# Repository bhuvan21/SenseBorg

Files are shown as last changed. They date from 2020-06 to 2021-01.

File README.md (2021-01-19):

# SenseBorg
A modular platform for human sensory substitution via haptic feedback.

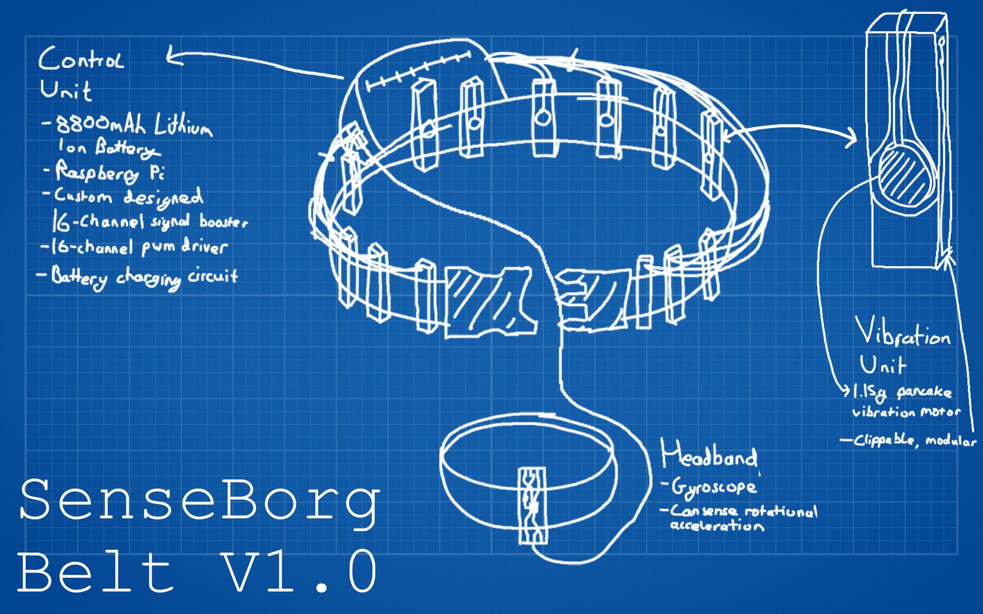
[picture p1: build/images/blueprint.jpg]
Blueprint


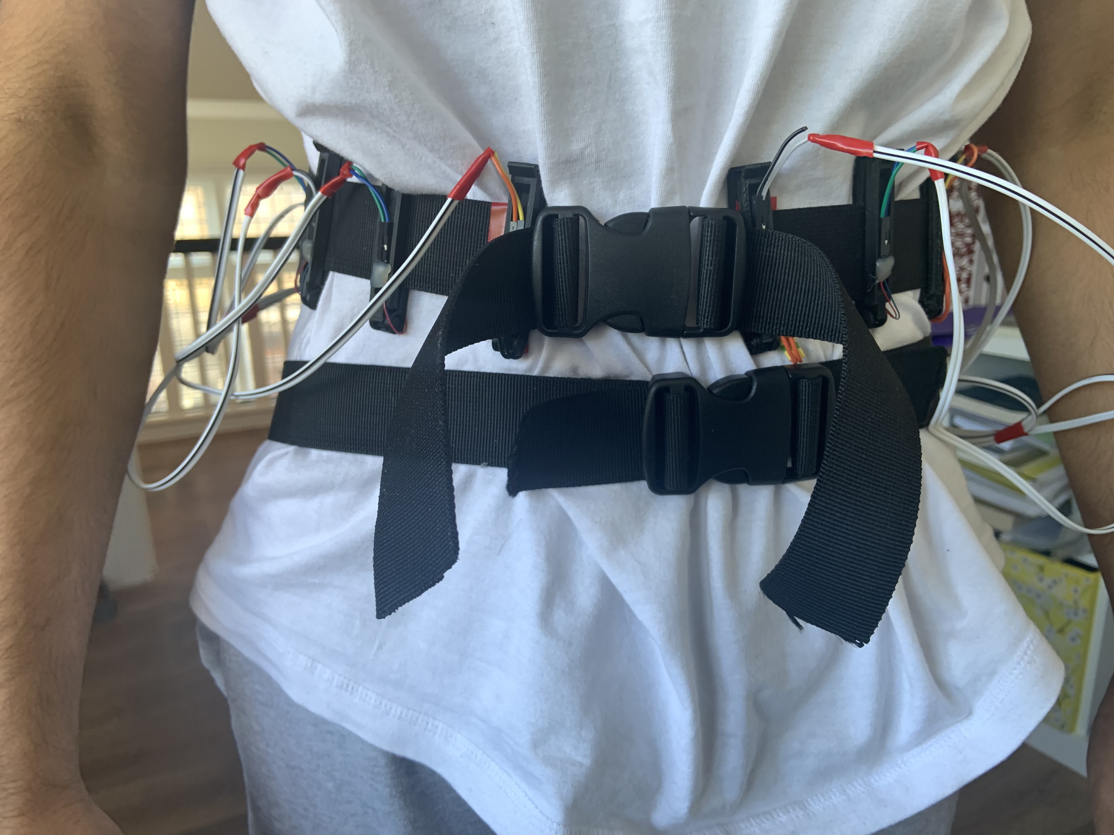
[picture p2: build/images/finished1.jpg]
Finished


## Introduction
The concept of sensory substitution involves supplying sensory stimuli through a sensory modality usually used for gathering different sensory data  – and has an important role to play in rehabilitation those with vestibular impairments. Sensory substitution requires the use of a specific device, which uses artificial sensors to collect sensory data, and delivers this data to a subject via one of their sensory modalities (e.g touch, audio, visual). Devices which do this are called sensory substitution devices (SSDs).

## The Project
Sensory Substitution Devices require two parts.  
1. Some way to provide artificial stimuli  
2. Some way to generate this stimuli (usually a sensor of some kind)  

Good examples of this are the BrainPort and feelSpace belt devices. My project nicknamed "SenseBorg" (think Senses + Cyborg) is my contribution to this under-explored area of research.  

These two parts of my project are:
1. A custom belt, with up to 16 embedded haptic motors, for generating artificial stimuli with selectable position and strength.  
2. An IMU headband for sensing rotational acceleration, as an approximation of the sense of balance.  

The second part of the project can be easily substituted for any other sensor, which could be used to conduct experiments into learning other sensorimotor contingencies.  
Thus, this project provides a platform for providing artificial stimuli for use in more general sensory substitution experiments.

## The Belt
The specifics of the physical hardware in the SenseBorg belt is more detailed in the build folder, specifically BUILD.md. However, the basic features are as follows.  
- 12h battery life
- 16 different motor channels, each with PWM control
- Wifi enabled
- Bluetooth capabilities
- Modular as haptic motors can be placed variably on the belt to accomodate for different waist sizes
- ~2A Charging rate (if your charger can handle it) for overnight charging

## This Repository
This repository contains the software and hardware information for the SenseBorg belt itself. Of course, a lot of the software is specific to interfacing with my specific sensor system, and translating this into targeted haptic feedback. Please have a look at build/BUILD.md for a build guide. This project is currently in it's first iteration, so is subject to change and improvement.

## Results
After a first experiment, the hypothesis that the wearing of this belt would result in an increase in the wearer's sense of balance, was shown to be statistically significant. (Balance was tested via a sharpened Romberg Test, the belt was worn over a week period for 12 hours a day, the statistical difference was measured via a T-test, and the final p < 0.01)
My research paper based on this device is undergoing a final review at the Young Scientists Journal.

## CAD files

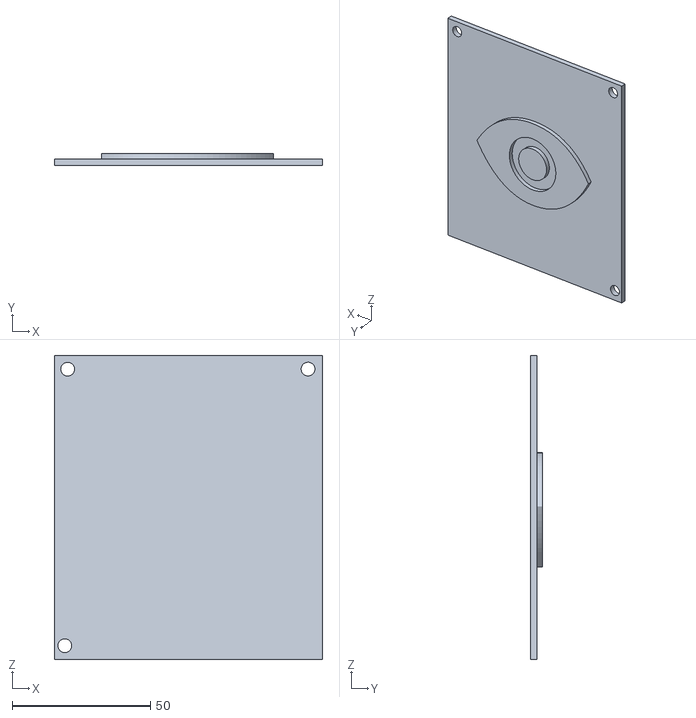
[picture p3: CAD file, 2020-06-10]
build/stls/top.stl
97.0 x 4.50 x 110.0

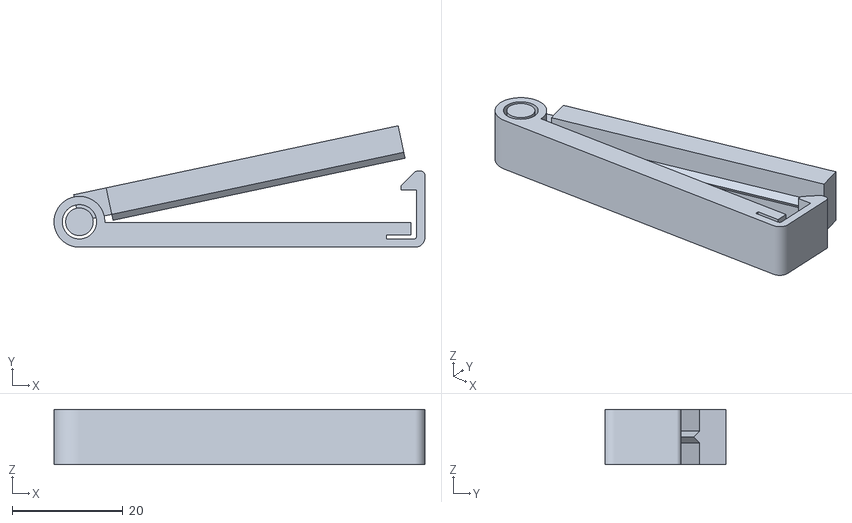
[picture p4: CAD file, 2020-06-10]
build/stls/clip.stl
67.1 x 22.0 x 10.0

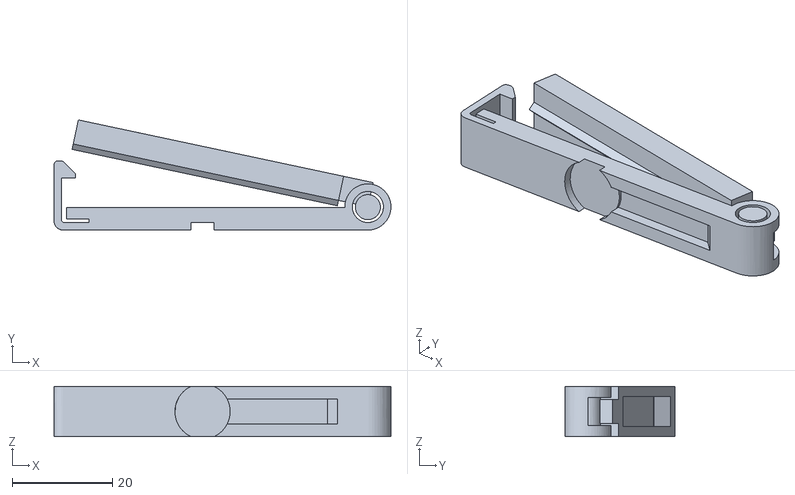
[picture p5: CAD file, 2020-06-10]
build/stls/motorclip.stl
67.1 x 21.9 x 10.0

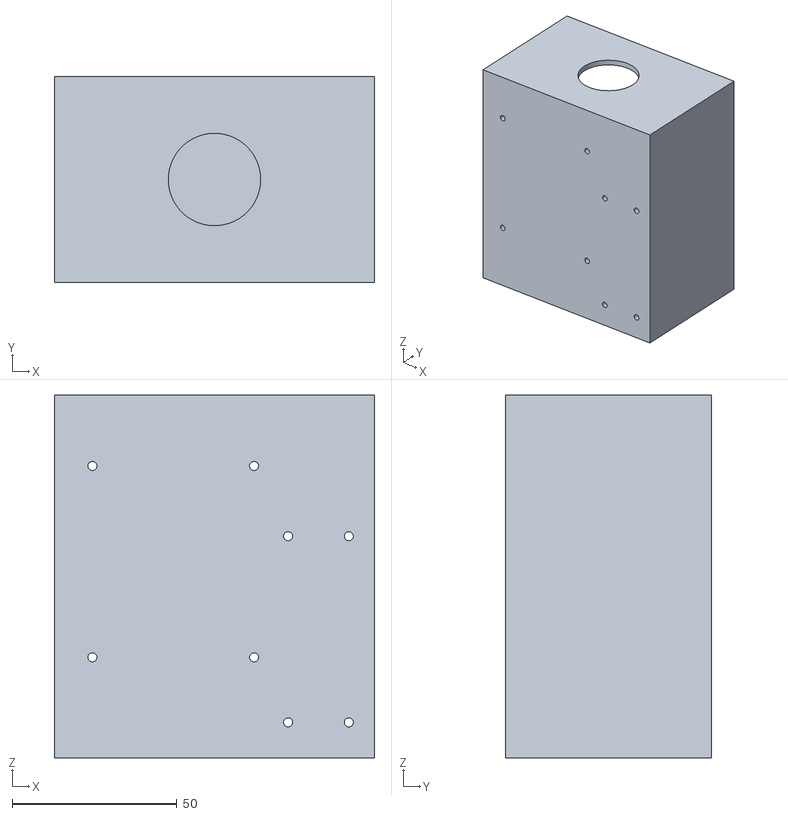
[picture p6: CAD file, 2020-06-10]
build/stls/box.stl
97.0 x 62.5 x 110.0

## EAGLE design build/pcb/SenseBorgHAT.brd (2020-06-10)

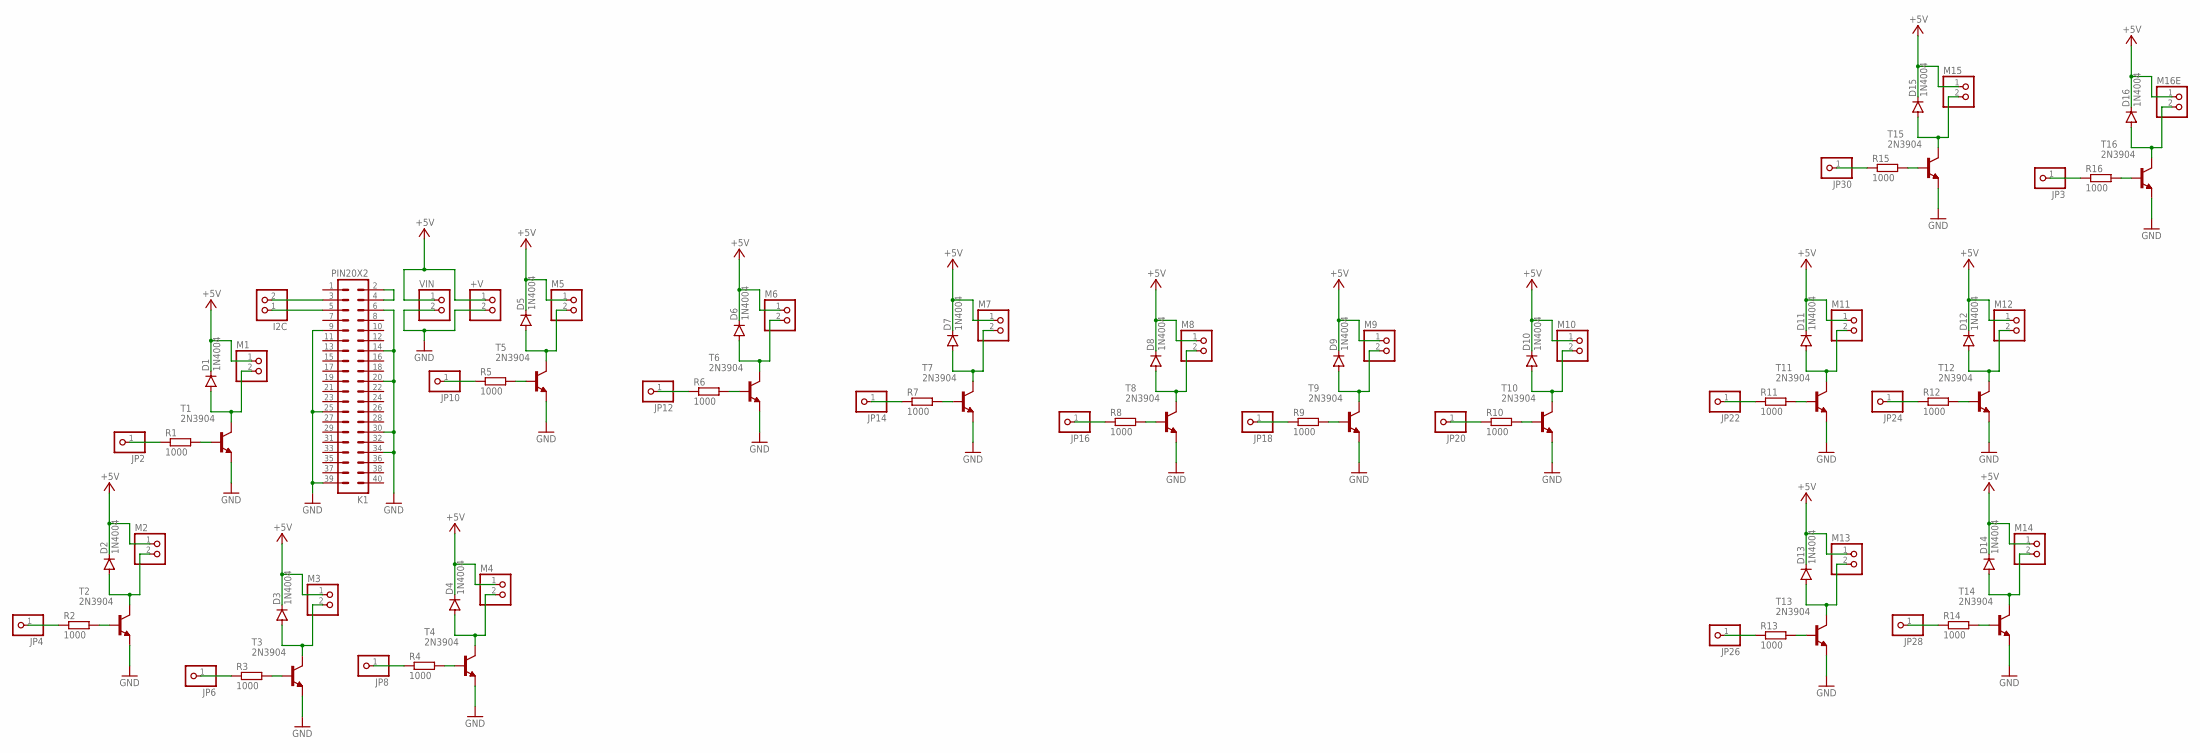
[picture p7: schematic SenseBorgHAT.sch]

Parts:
+V: PINHD-1X2; 1X02
D1, D2, D3, D4, D5, D6, D7, D8, D9, D10, D11, D12, D13, D14, D15, D16: 1N4004; DO41-10
I2C: PINHD-1X2; 1X02
JP2, JP3, JP4, JP6, JP8, JP10, JP12, JP14, JP16, JP18, JP20, JP22, JP24, JP26, JP28, JP30: PINHD-1X1; 1X01
K1: PIN20X2; PIN_20X2
M1, M2, M3, M4, M5, M6, M7, M8, M9, M10, M11, M12, M13, M14, M15, M16E: PINHD-1X2; 1X02
R1, R2, R3, R4, R5, R6, R7, R8, R9, R10, R11, R12, R13, R14, R15, R16: 1000; 0207/10
T1, T2, T3, T4, T5, T6, T7, T8, T9, T10, T11, T12, T13, T14, T15, T16: 2N3904; TO92
VIN: PINHD-1X2; 1X02

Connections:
+5V: +V.1, D1.C, D2.C, D3.C, D4.C, D5.C, D6.C, D7.C, D8.C, D9.C, D10.C, D11.C, D12.C, D13.C, D14.C, D15.C, D16.C, M1.1, M2.1, M3.1, M4.1, M5.1, M6.1, M7.1, M8.1, M9.1, M10.1, M11.1, M12.1, M13.1, M14.1, M15.1, M16E.1, VIN.1
+5V1: I2C.1, K1.5
GND: +V.2, K1.6, K1.9, K1.14, K1.20, K1.25, K1.30, K1.34, K1.39, T1.3 (E), T2.3 (E), T3.3 (E), T4.3 (E), T5.3 (E), T6.3 (E), T7.3 (E), T8.3 (E), T9.3 (E), T10.3 (E), T11.3 (E), T12.3 (E), T13.3 (E), T14.3 (E), T15.3 (E), T16.3 (E), VIN.2
M15: D10.A, M10.2, T10.1 (C)
unnamed: R1.2, T1.2 (B)
unnamed: D1.A, M1.2, T1.1 (C)
unnamed: JP2.1, R1.1
unnamed: R2.2, T2.2 (B)
unnamed: D2.A, M2.2, T2.1 (C)
unnamed: JP4.1, R2.1
unnamed: R3.2, T3.2 (B)
unnamed: D3.A, M3.2, T3.1 (C)
unnamed: JP6.1, R3.1
unnamed: R4.2, T4.2 (B)
unnamed: D4.A, M4.2, T4.1 (C)
unnamed: JP8.1, R4.1
unnamed: R5.2, T5.2 (B)
unnamed: D5.A, M5.2, T5.1 (C)
unnamed: JP10.1, R5.1
unnamed: R6.2, T6.2 (B)
unnamed: D6.A, M6.2, T6.1 (C)
unnamed: JP12.1, R6.1
unnamed: R7.2, T7.2 (B)
unnamed: D7.A, M7.2, T7.1 (C)
unnamed: JP14.1, R7.1
unnamed: R8.2, T8.2 (B)
unnamed: D8.A, M8.2, T8.1 (C)
unnamed: JP16.1, R8.1
unnamed: R9.2, T9.2 (B)
unnamed: D9.A, M9.2, T9.1 (C)
unnamed: JP18.1, R9.1
unnamed: R10.2, T10.2 (B)
unnamed: R16.2, T16.2 (B)
unnamed: JP20.1, R10.1
unnamed: R11.2, T11.2 (B)
unnamed: D11.A, M11.2, T11.1 (C)
unnamed: JP22.1, R11.1
unnamed: R12.2, T12.2 (B)
unnamed: D12.A, M12.2, T12.1 (C)
unnamed: JP24.1, R12.1
unnamed: R13.2, T13.2 (B)
unnamed: D13.A, M13.2, T13.1 (C)
unnamed: JP26.1, R13.1
unnamed: R14.2, T14.2 (B)
unnamed: D14.A, M14.2, T14.1 (C)
unnamed: JP28.1, R14.1
unnamed: R15.2, T15.2 (B)
unnamed: D15.A, M15.2, T15.1 (C)
unnamed: JP30.1, R15.1
unnamed: D16.A, M16E.2, T16.1 (C)
unnamed: JP3.1, R16.1
unnamed: I2C.2, K1.3
unnamed: K1.2, K1.4

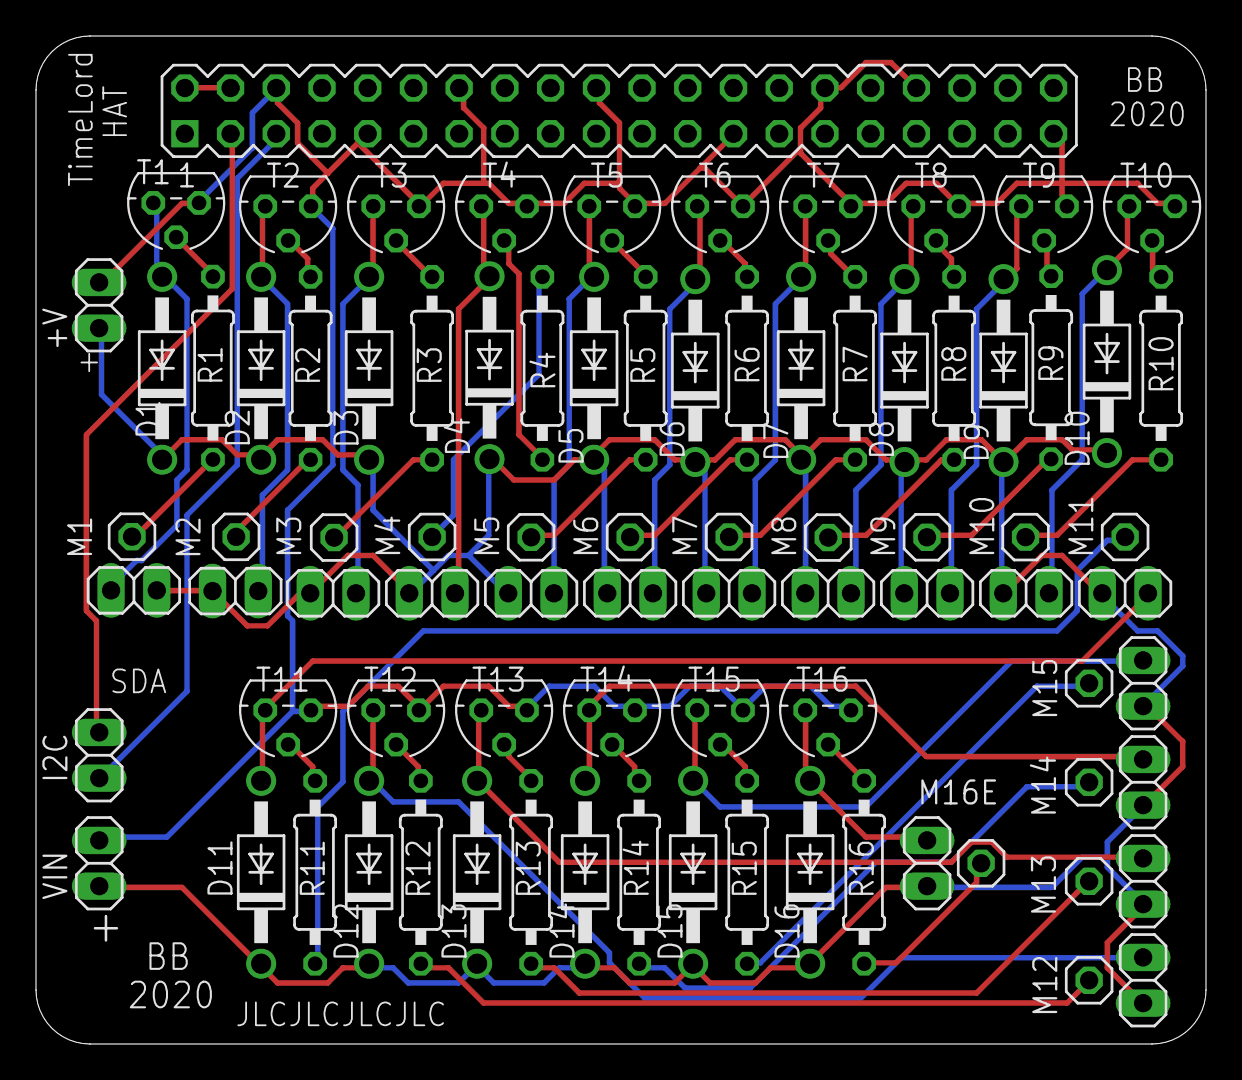
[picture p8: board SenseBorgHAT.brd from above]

Board: 2 copper layers, 65.0 x 56.0 mm, 84 parts (0 on the bottom side), 53 nets.

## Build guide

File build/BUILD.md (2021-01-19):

# Build Guide
I appreciate this guide is very long, but it contains all the information needed to build one SenseBorg Belt, and my IMU headband.  
Please read the whole guide, as I'll admit not all information is placed in the best order (but it is all here)

Blueprint

## Tools You Will Need
- A lot of patience and time
- Soldering station (be safe!)
- Hot glue gun or superglue
- Wire Stripper (or scissors if you're willing)
- 3D printer (or use an online service)
- PCB Manufacture (use an online service)

## Parts
- Raspberry Pi 3B with micro SD card (Micro Controller)
- Powerboost 1000C (Li-Po Charger)
- 8800mAh Li-Po Battery
- 16 Channel PWM Driver (interface over I2C)
- SenseBorg HAT PCB
- Raspberry Pi HAT header pins
- Male Breakaway headers (quite a few ~50 pins, pin spacing 2.54mm)
- 16 NPN Transistors (max current at least 200mA, max voltage at least : 10V)
- 16 Resistors (1K, 0.25W)
- 16 Diodes (optional flyback, max current at least : 200mA, max voltage at least : 10V)
- 16 Pancake Haptic Motors (around 1G force, 5V, current draw max ~100mA)
- Backpack straps with buckle ends (used for the belt)
- M5 self tapping screws (up to 65mm length)
- M2.5 Nuts and Bolts (8 of each, length up to 30mm)
- LOTS of Female jumper cables (>50)
- 9DOF Accelerometer (interface over I2C)
- Lots of wire (~20m)
- Heatshrink (ideally)
- Hot Glue sticks (ideally)
- 3D Printed custom parts
- A fanny pack

## Making the SenseBorg HAT
The SenseBorg HAT is the main electronics control hub in this project. It serves primarily as a signal booster for the haptic motors, with 16 distinct inputs and outputs. Signals given as inputs are switched from the main Li-Po power supply, so can draw much more current than the PWM driver can provide, which the motors require.
The HAT also breaks out extra power pins, and I2C pins, and has jumper headers for motors and PWM signals to plug into.

1. Download the PCB files from the build folder of this respository.
2. Either open the .brd files in Eagle and export gerber files as required by your PCB making service, or use the gerber files provided.
3. Get the PCB made, and delivered.
4. Solder the transistors, resistors, diodes and headers.
5. You should now be left with a functional SenseBorg HAT.

|  1  |  2  |  3  |
|:---:|:---:|:---:|
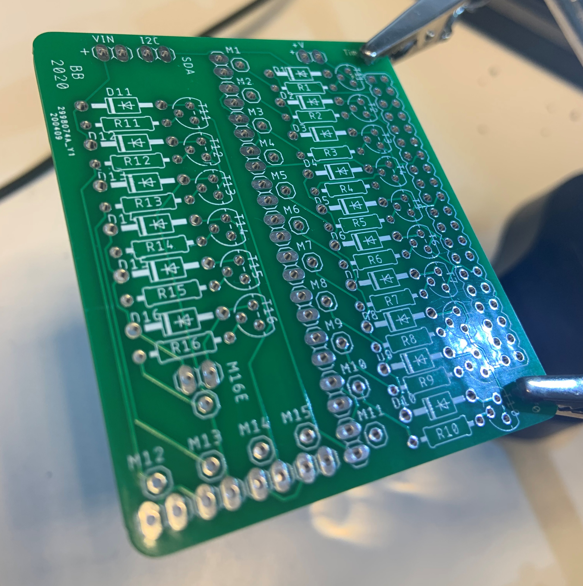
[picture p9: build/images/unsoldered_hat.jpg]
Blank HAT
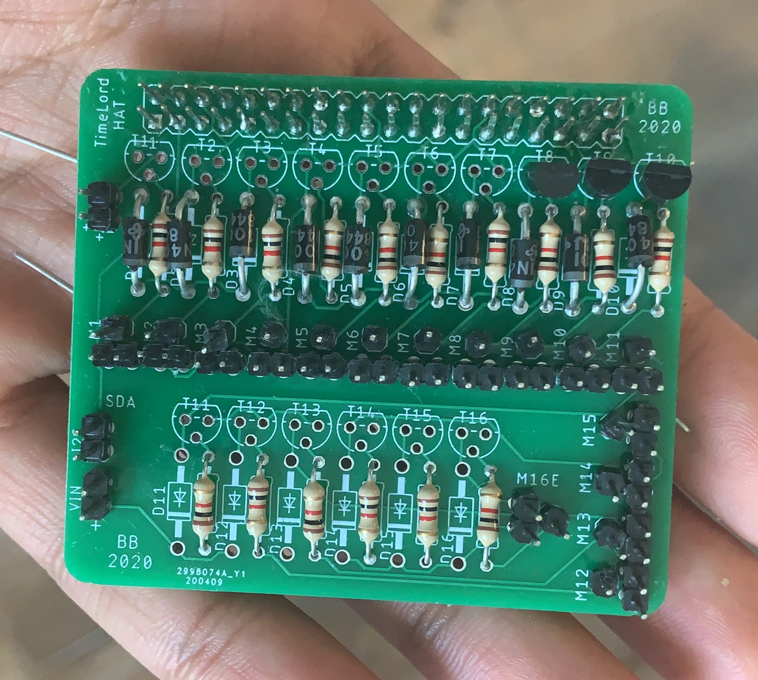
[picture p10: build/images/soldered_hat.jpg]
Soldered HAT
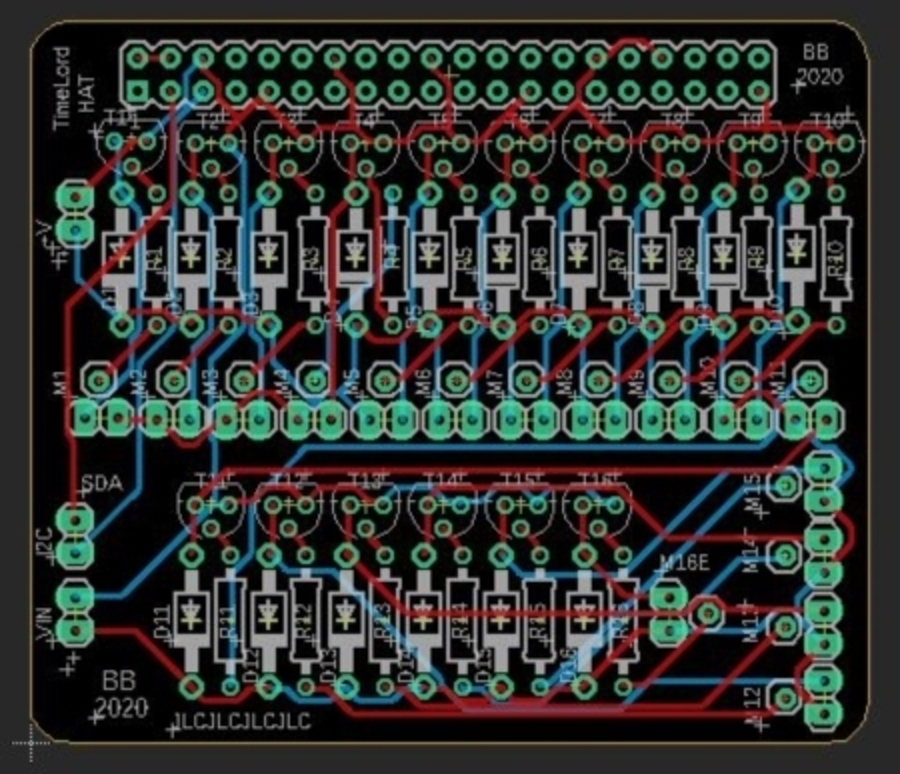
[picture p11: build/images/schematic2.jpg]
Schematic PCB
|  |  |  |

## Making the Motor Clips
Each haptic motor is part of a motor clip. These motor clips clip around the belt at regular intervals, with the motors facing towards to wearer. This solution allows for a variable number of motors and placements. This helpes the belt work for all waist sizes. Each motor clips requires:
- 3D Printed Motor Clip
- Pancake Vibration Motor
- 2 breakaway headers

1. 3D print the Motor Clip (found in motorclip.stl)
2. Solder the ends of the wires on the pancake motor to the two breakaway headers. Use heatshrink (ideally)
3. If your motor has adhesive on the back, pull off the protective tab and stick the pancake motor into the circular indent on the clip. The wires from the motor should be facing towards the indented rectangle on the clip (towards the pivot of the clip).
4. Wrap the wires around the pivot of the clip, so that the headers rest parallel to the clip on the other side, in the provided indent. Secure them in place with glue of some kind.

You should now have finished a single motor clip. You will need ~16 of these.

|  1  |  2  |
|:---:|:---:|
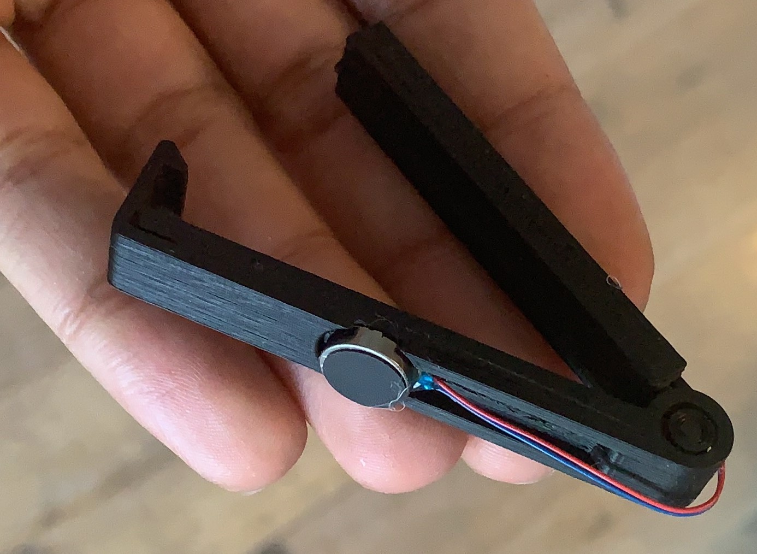
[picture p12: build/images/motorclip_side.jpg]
Motor Clip Side
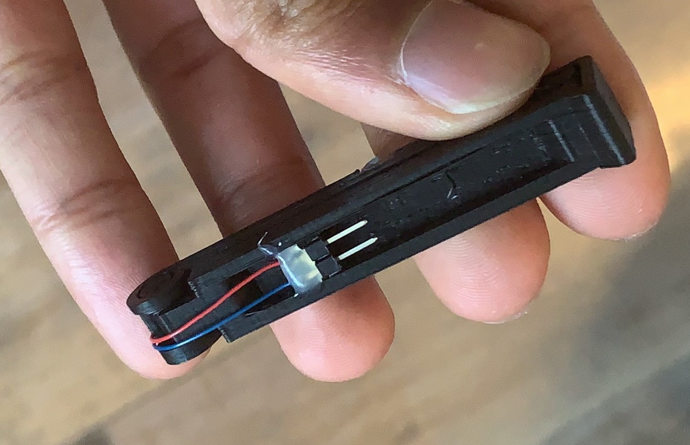
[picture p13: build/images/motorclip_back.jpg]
Motor Clip Back
|  |  |

## Board Arrangement
There is probably a better way of arranging all these boards, but improvements will come in V2.
The box and its top will need to be 3D printed (see box.stl and top.stl)
Below is a diagram of where the boards should go, and a picture of what this looks like.
Ideally all the nuts and bolts will hold everything in place, but feel free to be liberal with glue if needed (an unfortunate reality)

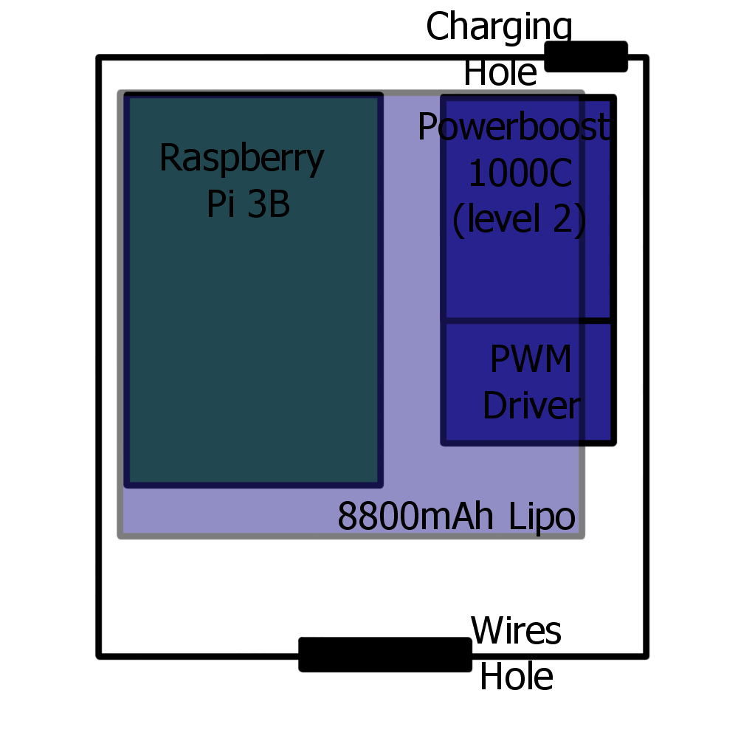
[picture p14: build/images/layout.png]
Layout


## Wiring Overview
This section lists all the wiring that needs to be done. I suggest doing all the soldering first, and then doing the wiring after placing all the boards into the container.
The whole system is powered by the 8800mAh Li-Po. This lipo plugs into the PowerBoost 1000C via the battery connector. If your battery doesn't have a connector, it can be soldered in to the BAT and GND connections. Also solder in headers to the adjacent 5V and GND connections. Finally cut your USB cable about 15cm from the micro USB end. Strip the cut end of the cable and isolate the power and ground wires. Solder these to the 5V and GND connections on the board. Since you've already soldered headers to the main breakouts, use the connections meant for a USB A header which we won't need for this project.

The Powerboost 1000C also boosts the Lipo's 3.3V to 5V, so this power needs to be connected to everything which needs power in the system. Use female-female jumpers to connect the PWR headers from the Powerboost 1000C to the VIN on the SenseBorg HAT. The USB cable will be plug into the Raspberry Pi to power it.

The SenseBorg HAT is placed onto the Raspberry Pi (as HAT's are). +5V, GND, SDA and SCL should be connected to the relevant pins on the 16 Channel servo driver (solder headers to this). Use these pins from the HAT's GPIO header pins, to save the extra I2C and PWR pins broken out for your I2C sensor.

Use female-female jumper cables to connect each PWM output from the 16 Channel PWM driver to each of the 16 inputs on the SenseBorg HAT (each input is the single pin on each triangle (the other two are for the motors)).

Use female-female jumper cables, spliced with longer wires to create super long (~70-90cm) female-female jumper cables to connect each motor output (each pair from the groups of 3 headers on the SenseBorg HAT), to the two pins on each motor clip. Polarity doesn't matter.
Use similarly long jumper cables to connect the broken out I2C and PWR pins to connect the pi to the I2C sensor.
These are all the electronic connections required. Have a look at photos for reference, and the circuit diagram (wiring.jpg) too.
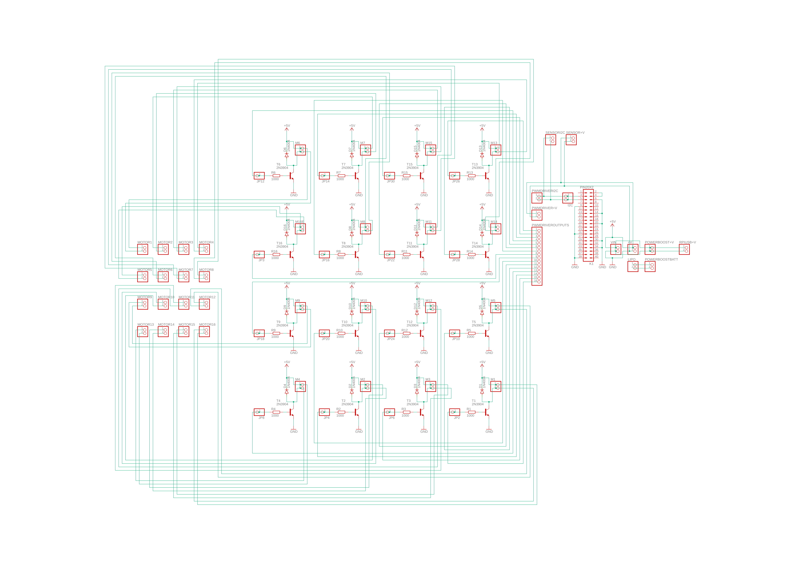
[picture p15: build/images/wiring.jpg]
Wiring


## Putting Together

1. Place all boards in as specified in the Board Arrangement section. Ensure they are held in place by the relevant nuts and bolts.
2. Plug the battery into the Powerboost, and place the battery outside the box.
3. Connect PWR from the HAT VIN with jumper wires.
4. Connect PWR and I2C from the HAT to the PWM driver.
5. Connect each of the 16 PWM outputs from the PWM driver to each of the 16 PWM inputs.
6. Connect each pair of 16 super long jumper cables (tape two together in the mid section to ensure you have both ends of a motor for each pair) to each of the double header motor outputs from the HAT.
7. Bring the ends of these 32 jumpers through the circular hole in the box and out.
8. Use 4 more of these long jumpers to connect to the broken out I2C and PWR on the HAT. Mark these with tape on their ends to avoid confusion with motor jumpers. Bring these out of the box the same way.
9. Plug the micro USB cable from the Powerboost into the pi.
10. Check all electronics are connected correctly (check Wiring Overview and circuit diagram)
11. Place the battery inside the box (should fit comfortably).
12. Place the lid on top of the box (may have to rotate or flip to get holes to line up)
13. Use the self tapping screws to secure the lid onto the box.
14. Connect each pair of motor long jumpers to the headers on a motor clip.
15. Connect the I2C connections to your I2C sensor.
16. Clip the clips uniformly around a length of backpack strap (should be the target waist length + a few inches for tightening). Be careful with how you route wires here, it will matter.
17. Add the buckle pieces on either end of the strap.
18. Cut another length of strapping, and add buckles to this too.
19. Attach this across the fanny pack in some way, with the pack attached at the middle of the belt.
20. Place the electronics box into the pack, and zip up as much as possible, whilst letting wires come out.
21. You may now need to adjust how you've routed your motor wires, to minimise crossovers, but you should now be done!

|  1  |  2  |  3  |  4  |
|:---:|:---:|:---:|:---:|
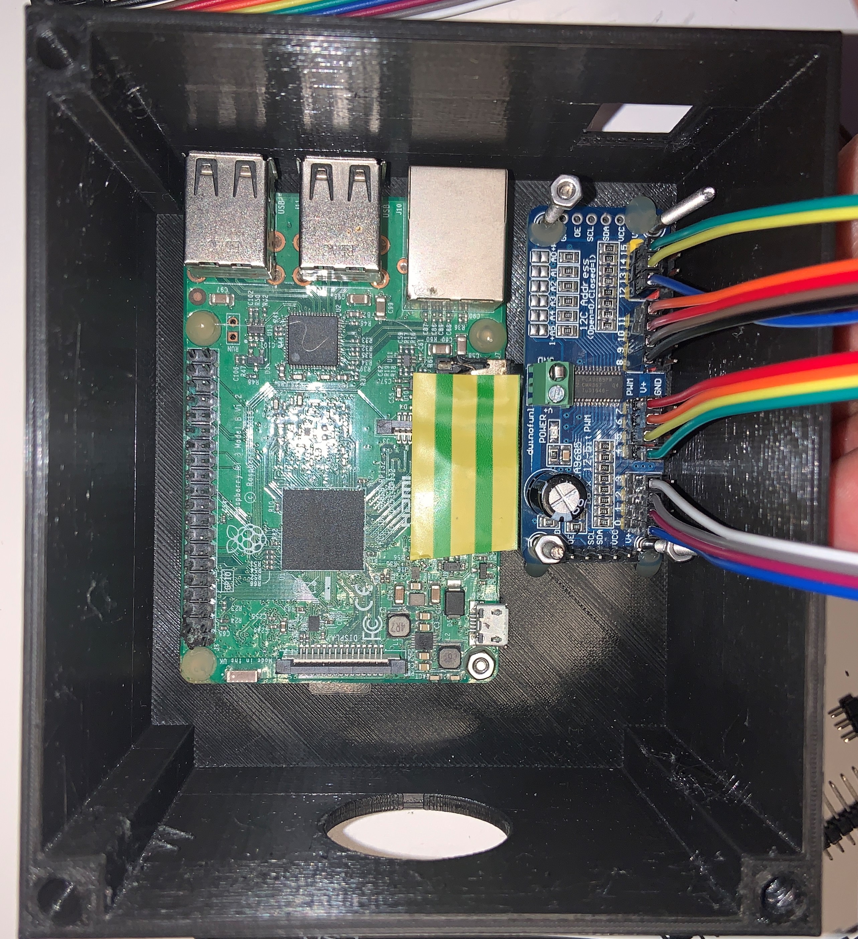
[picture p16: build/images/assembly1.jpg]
Assembly 1
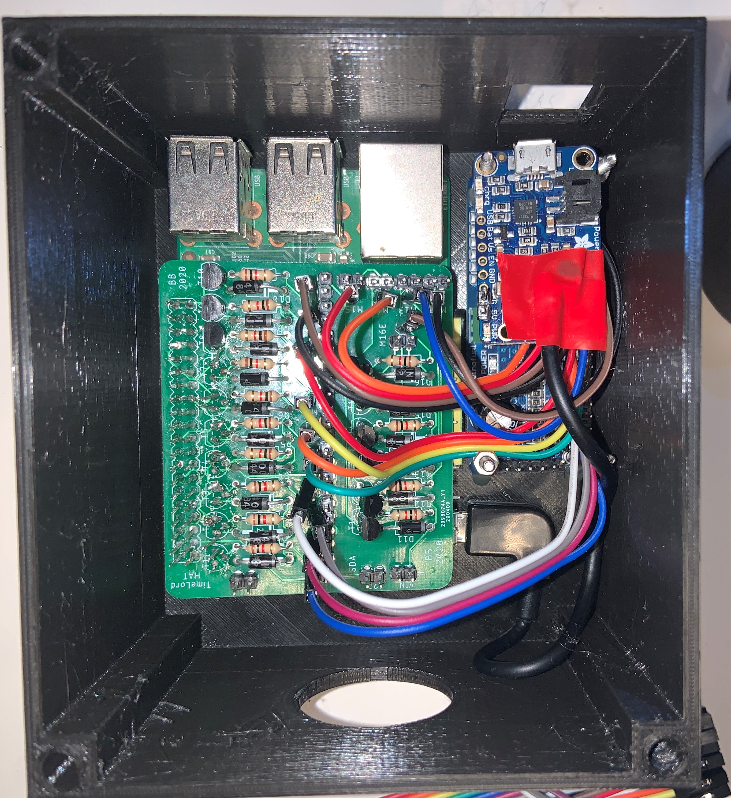
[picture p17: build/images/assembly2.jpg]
Assembly 2
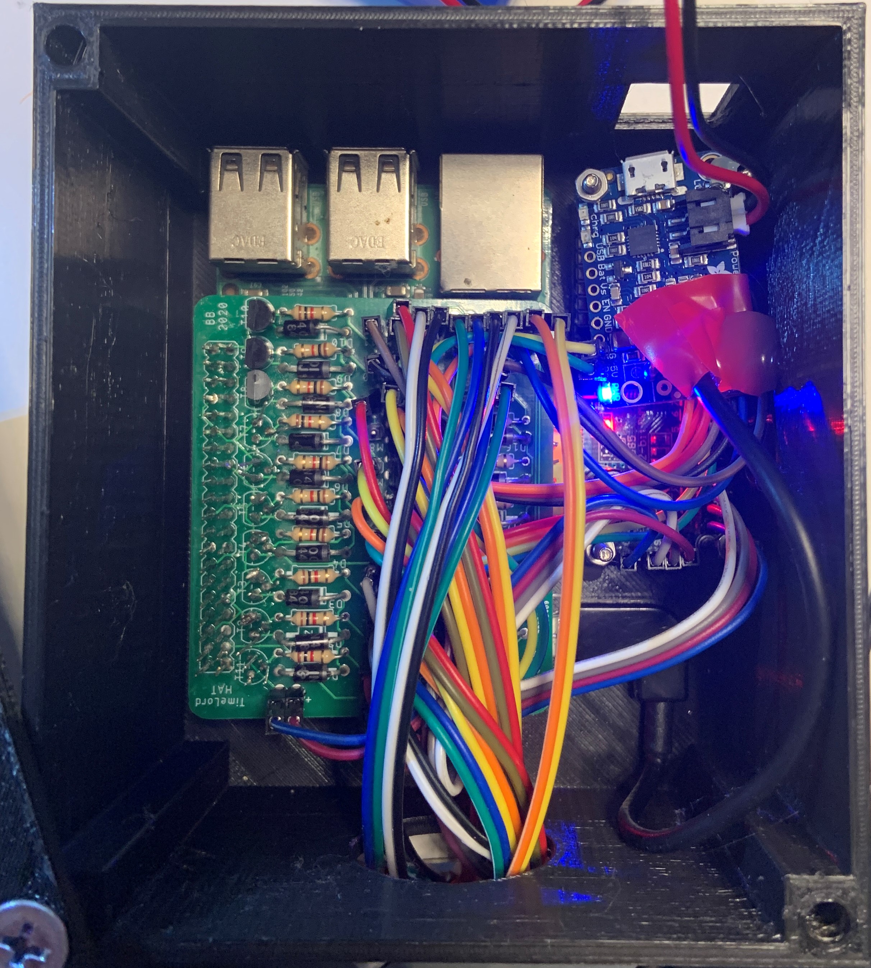
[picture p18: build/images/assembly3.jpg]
Assembly 3
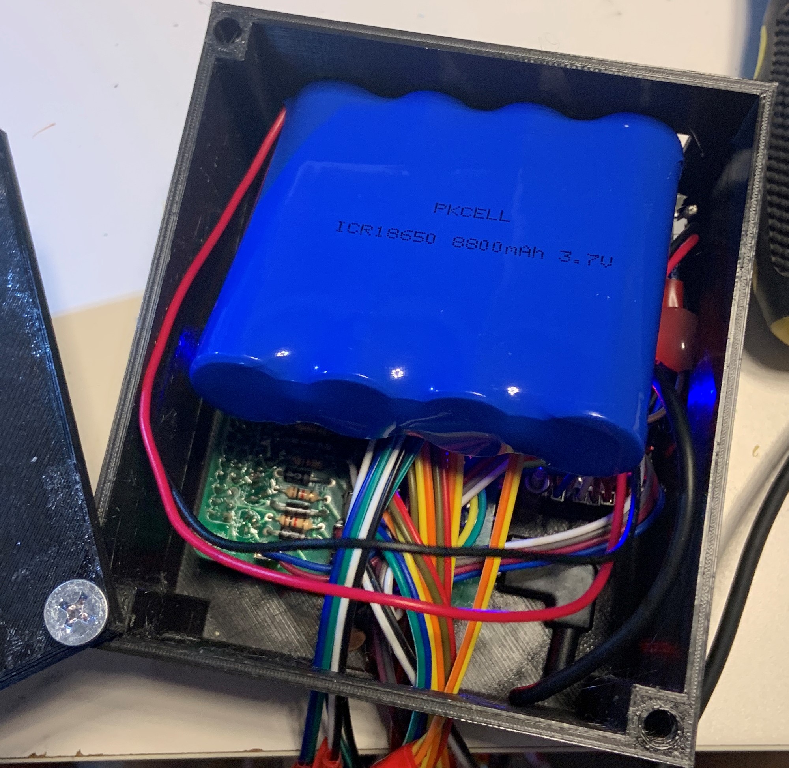
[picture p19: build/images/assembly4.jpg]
Assembly 4
|  |  |  |  |

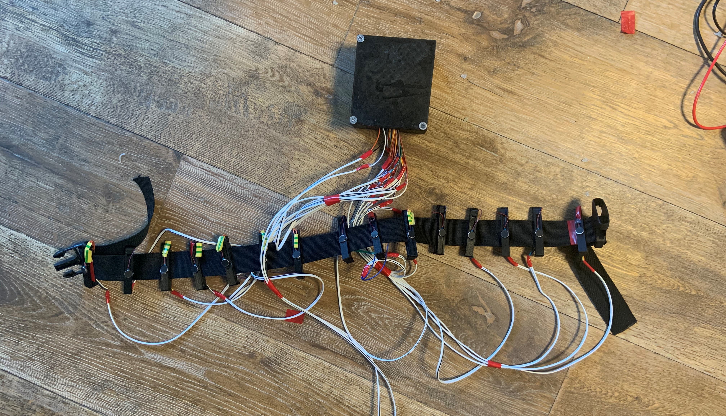
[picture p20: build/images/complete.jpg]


|  1  |  2  |
|:---:|:---:|
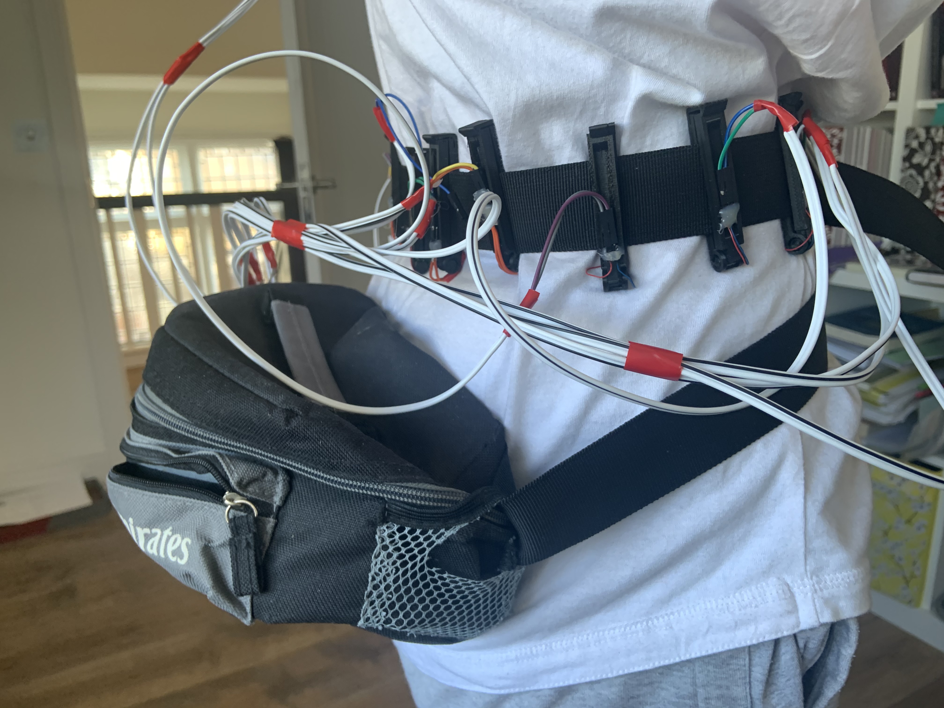
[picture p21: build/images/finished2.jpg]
Finished
| Finished |  |

To put on the belt, first attach the belt holding the electronics pack, then the belt with the motors. Ensure the two belts do not overlap, and are around your midsection. It may be easier to do this whilst standing up!

Congrats, the belt is now done from a hardware standpoint! If you would also like to make the headband I did, to approximate the sense of balance, instructions are below.
Have a look at the Belt class to see how the code works. You will likely have to use calibrate_order.py to determine which PWM outputs map to which motors, so that they can be interfaced with smoothly. Once all done, edit test_main.py and go for it! If you are using a different sensor, you'll have to implement your own mainloop, similar to my example

## IMU Headband
Acquire a regular head/hair band. It should be thin, so that a clip can fit on it.
1. 3D Print a regular clip (clip.stl)
2. Secure an IMU either of the clip's flat faces. (glue)
3. Clip the clip onto the headband such that when word, the IMU is position near the back of the head, straight up.
4. Connect the long jumper I2C and PWR connections to the IMU.

|  1  |  2  |
|:---:|:---:|
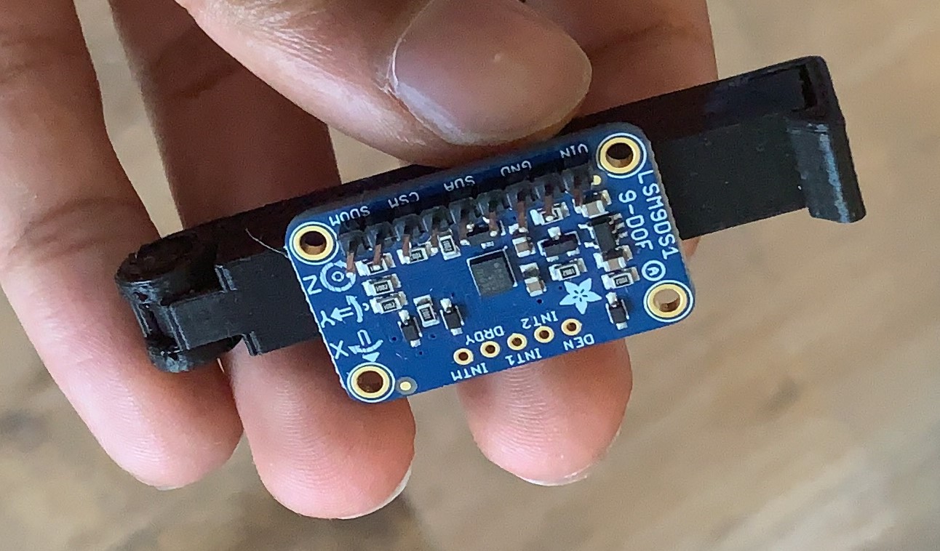
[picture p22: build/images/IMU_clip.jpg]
IMU Clip
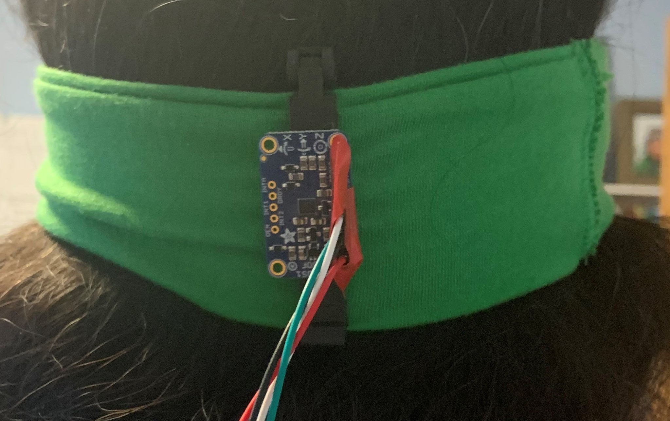
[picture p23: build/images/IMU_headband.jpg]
IMU Headband
|  | ) |

## Acknowledgements
All the research I read which inspired me to make this project - specifically BrainPort and the feelSpace belt.  
MasterFX's PLA compatible clip design, which I used and remixed - https://www.thingiverse.com/thing:330151  
And of course to Prabha Kotiswaran, for being my first test subject, without whom this experiment would not have been possible.
Dr Jane Evans (Project Supervisor)'s advice was also very helpful.  
Thomas Fossati's advice on networking for sending data wirelessly was also v. helpful.

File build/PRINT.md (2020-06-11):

# Print Guide

There are a few different parts which need to be 3D printed for this build.  

The box is made of box.stl and top.stl.
Both can be printed with ~15% infill or higher, these parts don't need to be super strong.  
Print orientation is pretty straightforward, print the box with the flat bottom side downwards, and the top with the eye facing upwards.  

The motor clips should be able to be printed as is, with the side for each clip facing downwards. There are slight small overhangs, but hopefully no supports should be needed for you. Try printing one, and if it fails, use supports. The clips print in place, so the axle should stay in the hole without sticking.  
The IMU clip is a normal clips, and should definitely not need supports.  

PLA works well for any of these prints, though if you can get your hands on ABS or PETG, that would probably be better.  
All of these prints shouldn't take too long, the clips are pretty small.

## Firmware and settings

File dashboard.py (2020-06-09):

import dash
import dash_core_components as dcc
import dash_html_components as html
from dash.dependencies import Input, Output

import plotly.graph_objs as go
import dataset

from time import time

db = dataset.connect('sqlite:///server/test.db')
table = db.load_table("table2")


# Step 1. Launch the application
app = dash.Dash()

# Step 2. Import the dataset
raw = table.find(order_by='time')
xs = []
ys = []
ys2 = []

for n, entry in enumerate(raw):
    if n == 0:
        print(entry)
    xs.append(entry["time"])
    ys.append(entry["gyroX"])
    ys2.append(entry["gyroZ"])
print(ys[-1], ys2[-1])


# Step 3. Create a plotly figure
trace_1 = go.Scatter(x = xs, y = ys,
                    name = 'GYROX',
                    line = dict(width = 2,
                                color = 'rgb(255, 0, 0)'))
trace_2 = go.Scatter(x = xs, y = ys2,
                    name = 'GYROZ',
                    line = dict(width = 2,
                                color = 'rgb(0, 0, 255)'))
layout = go.Layout(title = 'Time Series Plot',
                   hovermode = 'closest')
fig = go.Figure(data = [trace_1, trace_2], layout = layout)

# Step 4. Create a Dash layout
app.layout = html.Div([
                dcc.Graph(id = 'plot_id', figure = fig)
                      ])

# Step 5. Add callback functions


# Step 6. Add the server clause
if __name__ == '__main__':
    app.run_server(debug = True)

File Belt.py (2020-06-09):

import math
import time

import board
import busio
import Adafruit_PCA9685

from utils.vector import *
from utils.Compass import Compass
from utils.Vibrations import Vibrations
from network import Sender

class Belt:
    def __init__(self, sensor=None, vibrations=None, i2c=None, units=None, order=None):
        if i2c == None:
            self.i2c = busio.I2C(board.SCL, board.SDA)
        else:
            self.i2c = i2c
        if sensor is None:
            self.sensor = Compass(i2c=self.i2c)
        else:
            self.sensor = sensor
        
        if vibrations is None:
            self.vibrations = Vibrations(units=units, order=order)
        else:
            self.vibrations = vibrations
        
        self.sender = Sender()

    def v1_mainloop(self):
        a = time.time()
        try:
            if self.sensor.sensor.raw:
                all = self.sensor.sensor.get_all()
                t = time.time()
                cut = all[3:6]
                self.sender.queue.put(cut[0]+cut[2]+cut[1]+[t], block=False)
                
            raw = all[5]
            print("gyro", time.time() - t)
            fb = -raw[0]
            lr = -raw[2]
            if abs(lr) >30 or abs(fb) > 40:
                angleraw = angle_between((0, 1, 0), (lr, fb, 0))
                angle = angleraw
                if angleraw < 0:
                    angle = (180 - abs(angleraw)) + 180
                print(angle)
                index = int(angle/24)
                if self.vibrations.on[index]:
                    return
                else:
                    for n, j in enumerate(self.vibrations.on):
                        if j:
                            self.vibrations.safe_pwm(n, 0, 0)

                    test = min(int(math.sqrt((fb**2) + (lr**2))/150*3000), 3000)
                    self.vibrations.safe_pwm(index, 0, test)

            else:
                for n, j in enumerate(self.vibrations.on):
                    if j:
                        self.vibrations.safe_pwm(n, 0, 0)
        except Exception as e:
            print(e)
            self.vibrations.all_off()

        print(time.time()-a)

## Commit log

2020-04-17 Sensor investigating
2020-05-12 i2c passthrough
2020-05-12 i2c passthrough2
2020-05-15 Sensor getting fixes + better networking
    [Belt.py, Sensor.py, network.py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]
2020-06-10 compacted assembly pics
2020-06-10 pcb things, circuit diagram, etc
    [SenseBorgHAT.brd, SenseBorgHAT.sch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]
2020-06-11 added print guide
